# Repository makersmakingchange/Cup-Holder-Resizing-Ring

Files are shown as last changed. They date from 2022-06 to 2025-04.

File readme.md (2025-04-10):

# Cup Holder Resizing Ring
The Cup Holder Resizing Ring is a 3D printed ring used to reduce the diameter of the opening of a cup holder. The design can be modified in OpenSCAD by inputing the appropriate dimensions.

Picture of Cup Holder Resizing Ring printed in black PLA.

## More info at
- [Makers Making Change Project Page](https://makersmakingchange.com/project/cup-holder-resizing-ring/)

## How to Obtain a Cup Holder Resizing Ring
### 1. Do it Yourself (DIY) or Do it Together (DIT)

This is an open-source assistive technology, so anyone is free to build it. All of the files and instructions required to build the <Device-Name> are contained within this repository. Refer to the Maker Checklist below.

### 2. Request a build of this device

If you would like to obtain a Cup Holder Resizing Ring , you may submit a build request through the [MMC Library Page](https://makersmakingchange.com/project/device-name/). The requestor is responsible for the cost of materials and any shipping.

### 3. How to build this device for someone else

If you have the skills and equipment to build this device, and would like to donate your time to create the switch for someone who needs it, visit the [MMC Maker Wanted](https://makersmakingchange.com/maker-wanted/) section.

## Getting Started

### 1. Read the Makers Checklist

[The Makers Checklist](https://github.com/makersmakingchange/Cup-Holder-Resizing-Ring/blob/main/Cup%20Holder%20Resizing%20Ring/Documentation/Cup_Holder_Resizing_Ring_Maker_Checklist.pdf) 

### 3. Print the 3D Printable components

The OpenSCAD file used to generate the device STL can be found in the [/Design_Files](/Design_Files) folder.

### 4. Put the ring into the intended cup holder.

## Files
### Documentation
| Document | Version | Link |
|---|---|---|
| Design Rationale | 1.02 | [Cup_Holder_Resizing_Ring_Design_Rationale](https://github.com/makersmakingchange/Cup-Holder-Resizing-Ring/blob/main/Cup%20Holder%20Resizing%20Ring/Documentation/Cup_Holder_Resizing_Ring_Design_Rationale.pdf) |
| Maker Checklist | 1.02 | [Cup_Holder_Resizing_Ring_Maker_Checklist](https://github.com/makersmakingchange/Cup-Holder-Resizing-Ring/blob/main/Cup%20Holder%20Resizing%20Ring/Documentation/Cup_Holder_Resizing_Ring_Maker_Checklist.pdf) | |
| 3D Printing Guide | 1.02 | [Cup_Holder_Resizing_Ring_3D_Printing_Guide](https://github.com/makersmakingchange/Cup-Holder-Resizing-Ring/blob/main/Cup%20Holder%20Resizing%20Ring/Documentation/Cup_Holder_Resizing_Ring_3D_Print_Guide.pdf) |
| User Guide | 1.02 | [Cup_Holder_Resizing_Ring_User_Guide](https://github.com/makersmakingchange/Cup-Holder-Resizing-Ring/blob/main/Cup%20Holder%20Resizing%20Ring/Documentation/Cup_Holder_Resizing_Ring_User_Guide.pdf) |
| Changelog | 1.02 | [Cup_Holder_Resizing_Ring_Changelog](https://github.com/makersmakingchange/Cup-Holder-Resizing-Ring/blob/main/Cup%20Holder%20Resizing%20Ring/Documentation/Cup_Holder_Resizing_Ring_ChangeLog.pdf) |

### Design Files
[CAD File](https://github.com/makersmakingchange/Cup-Holder-Resizing-Ring/tree/main/Cup%20Holder%20Resizing%20Ring/Design_Files)

## Attribution
Designers:
 - Makers Making Change

## License
Everything needed or used to design, make, test, or prepare the Cup Holder Resizing Ring is licensed under the CERN 2.0 Permissive license <https://ohwr.org/project/cernohl/wikis/Documents/CERN-OHL-version-2> (CERN-OHL-P) . 

<br /><span xmlns:dct="http://purl.org/dc/terms/" property="dct:title"><Device-Name></span> by <a xmlns:cc="http://creativecommons.org/ns#" href="www.makersmakingchange.com" property="cc:attributionName" rel="cc:attributionURL">Neil Squire</a> is licensed under a <a rel="license" href="http://creativecommons.org/licenses/by-sa/4.0/">Creative Commons Attribution-ShareAlike 4.0 International License</a>.

---
<!-- ABOUT MMC START -->
## About Us
Makers Making Change Logo

Makers Making Change is an initiative of [Neil Squire](https://www.neilsquire.ca/), a Canadian non-profit that helps people with disabilities.

We are committed to creating a network of volunteer makers who support people with disabilities in their communities through 3D printing assistive devices. Check out our library of free, open-source assistive technologies with parts and build instructions.

 - Website: [www.MakersMakingChange.com](https://www.makersmakingchange.com/)
 - GitHub: [https://github.com/makersmakingchange](https://github.com/makersmakingchange)
 - Twitter: [@makermakechange](https://twitter.com/makermakechange)
 - Instagram: [@makersmakingchange](https://www.instagram.com/makersmakingchange)

## How you can get involved
1. Help design a solution 
2. Help build a device request

## Contact Us

For technical questions, to get involved, or share your experience we encourage you to visit the [MMC Website](https://www.makersmakingchange.com/), [MMC Forum](https://makersmakingchange.com/forum), or contact info@makersmakingchange.com

<!-- ABOUT MMC END -->

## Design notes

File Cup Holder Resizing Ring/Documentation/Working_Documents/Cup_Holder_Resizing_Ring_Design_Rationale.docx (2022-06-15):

# Introduction

There are many open-source and commercial options available for cup holders, as well as built in cup holders on many structures and devices. However, with the varying sizing of beverages you can buy today, some cup holders will not hold your drink securely, so a way to modify the size is required.

# Research

There are many existing cup holder designs as well as a few open-source ones. Some models are adjustable, but typically cost more or are expensive/difficult to make.

https://makersmakingchange.com/resource/device-selection-guide-cup-holders/ - Contains many of the existing commercial devices found during research as well as the opensource devices in the MMC library.

Adjustable Ram Mount Cup Holder $73.69 (https://www.amazon.ca/RAM-Mounts-RAP-B-417BU-Level-Diameter/dp/B01N2Y8ZJQ?s=sports) – Is adjustable to fit various beverage containers, but very high in cost.

# Requirements

1. Shall be able to modify the size of existing cup holders.
2. Shall be easy to vary the dimensions to custom fit for different cup holders and beverage containers.

# Ideation

Component 1:

Resizing Ring: A custom printed ring that fits into the cup holder and effectively reduces the diameter of the cup holder to better fit a smaller beverage container.

# Prototyping

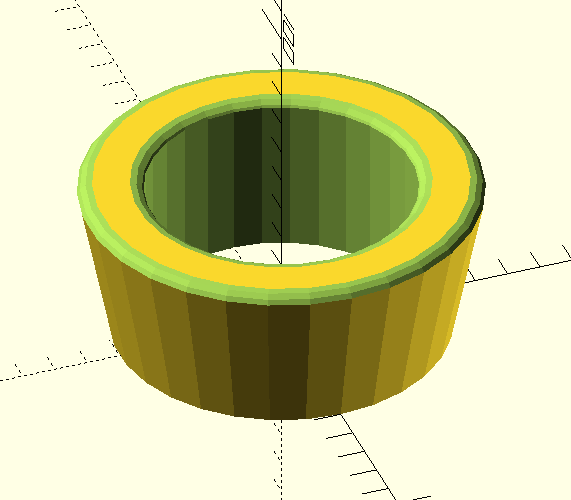
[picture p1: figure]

Designed in OpenSCAD, the Cup Holder Resizing Ring can be modified according to the measurements of the top and bottom radii, and height of the cup holder, as well as the radii of where the beverage container will sit in the holder.

# Final Design

- Updated the OpenSCAD file to include sliders for adjusting dimensions, and added dimensions for specific cup holders to the user quick guide and 3D print guide.
- Increased the resolution of the OpenSCAD model
- Changed the measurement input in the model from Radius to Diameter.

# Opportunities for Improvement

- Increase the number of presets
- Make the design so it can accommodate varying sizes of beverage containers once printed
  - Soft flaps or varying radius (like a camera iris)
- Add in the option for a bottom so open-ended cup holders can hold cans.

# Credited Resources Used In Development

- Idea came from Marc Hache and the ring he made for the cup holder in his Walker tray design.

© 2021 by Neil Squire. This work is licensed under the CC BY SA 4.0 License: http://creativecommons.org/licenses/by-sa/4.0 Files available at https://makersmakingchange.com/project/cup-holder-resizing-ring/ Page 1 of 1

V1.02 | June 2022 Cup Holder Resizing Ring Design Rationale

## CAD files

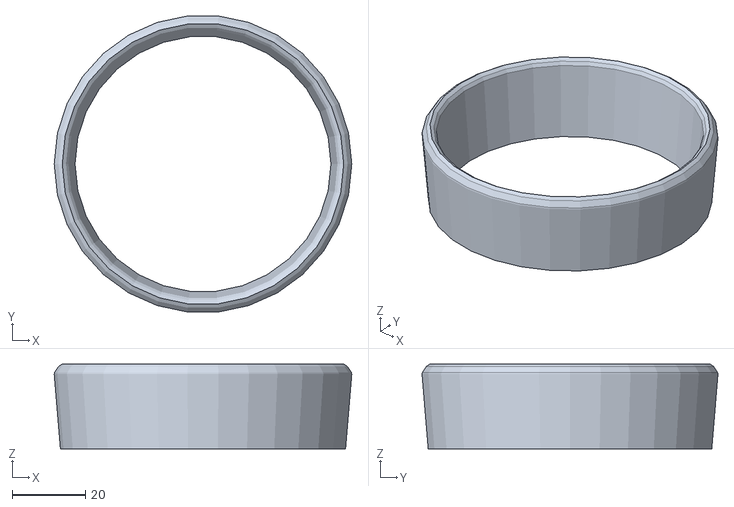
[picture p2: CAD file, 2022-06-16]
Cup Holder Resizing Ring/Design_Files/Example STL for Universal Travel Coffee Gimbal.stl
81.4 x 81.0 x 23.2

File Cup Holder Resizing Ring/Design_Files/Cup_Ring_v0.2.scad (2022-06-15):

// Cup Holder Adapter
//
// Written by Neil Squire / Makers Making Change
// This work is licensed under the CC BY SA 4.0 License: http://creativecommons.org/licenses/by-sa/4.0 

//  Files available at https://makersmakingchange.com/project/cup-holder-resizing-ring/

//
// This design is used to create a 3D printed adapter to reduce the size of a hole in a cup/bottle holder to better sure the beverage container.
//
//


/*[Cup Dimensions]*/
Lower_Cup_Diameter=40; // Lower cup diameter [mm]
Upper_Cup_Diameter=40; //  Upper cup diameter [mm]

/*[Holder Dimensions]*/
Lower_Holder_Diameter=50; // Lower holder radius [mm]
Upper_Holder_Diameter=60; // Upper holder  radius [mm]
Height=50; //          Holder depth [mm]



/*[Hidden]*/

// Misc variables
fudge = 0.005;

$fa=0.5;

difference() // A - B
{
    difference() // A
    {          
        difference() 
        {           
            cylinder(Height,Lower_Holder_Diameter/2,Upper_Holder_Diameter/2);
            cylinder(Height+fudge*2,Lower_Cup_Diameter/2,Upper_Cup_Diameter/2);
        }            
        rotate([0,180,0])
        {
            rotate_extrude()
            {
                translate([Upper_Cup_Diameter/2+4,-Height+5,0])
                {  
                    difference()
                    {
                        translate([-5,-5,0])
                        square(5,5);    
                        circle(r=5);
                    }
                }
            }
        }   
    }
    rotate([0,0,0]) // B
    {
        rotate_extrude()
        {
            translate([Upper_Holder_Diameter/2-5,Height-5,0])
            {
                difference()
                {   
                    translate([0,0,0])
                    square(5,5);   
                    circle(r=5);
                }
            }
        }
    }
}

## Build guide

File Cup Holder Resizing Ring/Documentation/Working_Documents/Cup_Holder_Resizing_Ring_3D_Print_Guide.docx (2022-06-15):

# 3D Printing Summary

Metrics | *Configuration 1*
Total Print Time (min) | Dependent on STL dimensions
Total Number of Components | 1
Typical Total Mass (g) | 100
Typical Number of Print Setups | 1

Specifications

Input the desired dimensions into OpenSCAD based on the cup and cup holder dimensions. Note that there are four radii and one height measurement. When measuring the radius, ensure the cup measurements line up with the height on the cup that should sit in the cup holder.

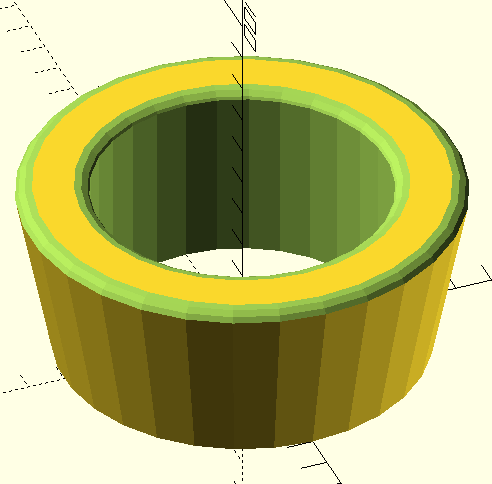
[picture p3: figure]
Photo showing the dimensions for editing the Cup Holder Resizing Ring.

Height

Lower Holder Diameter

Lower Cup Diameter

Upper Holder Diameter

Upper Cup Diameter

Cup Holder | Lower Diameter [mm] | Upper Diameter [mm] | Height [mm]
Cup Holder for Walker (https://makersmakingchange.com/assistive-devices/?_sf_s=cup%20holder) | 78 | 81 | 64
Swivel Wheelchair Cup Holder (https://makersmakingchange.com/project/swivel-wheelchair-cup-holder/) | 74 | 74 | 85
Universal Travel Coffee Gimbal (https://makersmakingchange.com/project/universal-travel-coffee-gimbal/) | 78 | 84 | 24

# 3D Printing Settings

Print File Name | Qty | Total Print Time (hr:min) | Mass (g) | Infill (%) | Support | Layer Height/ Nozzle Diameter(mm) | Notes
Cup_Ring_v0.2.stl | 1 | Dependent on STL dimensions. Likely 1 hour minimum | Dependent on STL dimensions. | 5 | N | 0.2/0.4 | Print in given orientation.

# Post-Processing

- Clean any stringing or filament strands from the print.

# Customization Options

- Ask the user if they have any colour preferences.
- Ask the user for the required dimensions to customize the STL appropriately to fit both their cup holder and beverage container.

# Examples of Quality Prints:

Photos of Component 1:

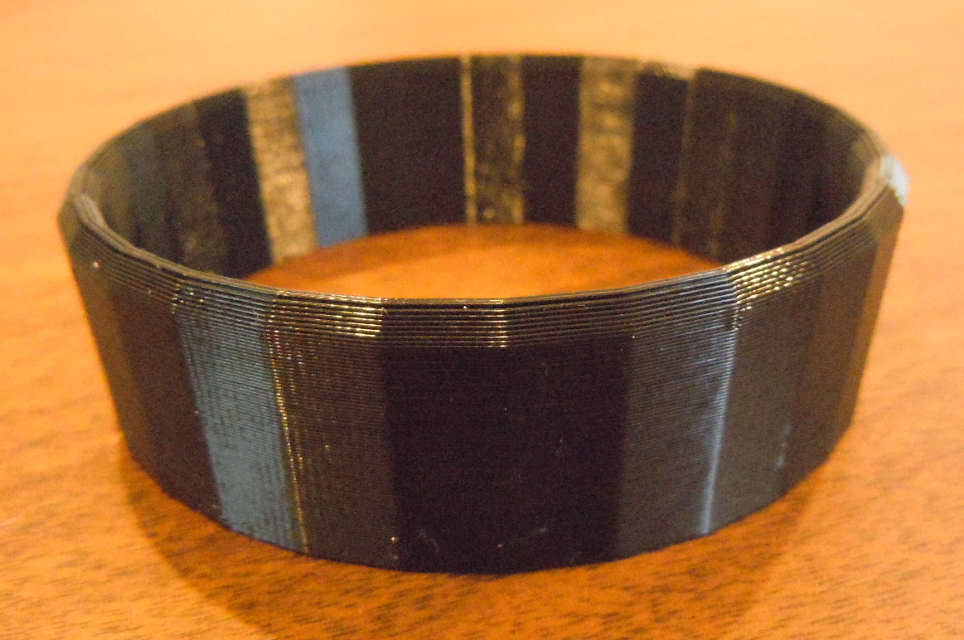
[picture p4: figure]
A picture containing an example of a quality print of the Cup Holder Resizing Ring.

© 2021 by Neil Squire. This work is licensed under the CC BY SA 4.0 License: http://creativecommons.org/licenses/by-sa/4.0 Files available at https://makersmakingchange.com/project/cup-holder-resizing-ring/ Page 1 of 2

V1.02 | June 2022 Cup Holder Resizing Ring 3D Printing Guide

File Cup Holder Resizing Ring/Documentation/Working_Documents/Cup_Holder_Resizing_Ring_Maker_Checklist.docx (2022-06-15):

# Maker To Do List

- Ask User Preferences for colour
- Ask user for beverage container dimensions and cup holder dimensions.
  - Depth of the Cup Holder
  - Inner radii at the top and bottom of the Cup Holder
  - Outer radii of the beverage container where it should line up with the top and bottom of the Resizing Ring.
- Print and deliver the device.

# Items to Give to User

- User Quick Guide
- Resizing Ring

© 2021 by Makers Making Change. This work is licensed under the CC BY SA 4.0 License: http://creativecommons.org/licenses/by-sa/4.0 Files available at https://makersmakingchange.com/project/cup-holder-resizing-ring/ Page 1 of 1

V1.02 | June 2022 Cup Holder Resizing Ring Maker Checklist

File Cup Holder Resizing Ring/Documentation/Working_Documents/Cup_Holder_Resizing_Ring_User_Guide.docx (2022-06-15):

## Introduction

The Cup Holder Resizing Ring is used to modify existing cup holders to hold smaller sized cups than intended. It can be used with mounted cup holders, or even built-in cups holders such as ones in a car.

## Features

The Cup Holder Resizing Ring decreases the inner diameter of a cup holder. It has rounded fillets on the upper edge to help guide the cup into place and reduce exposed sharp corners.

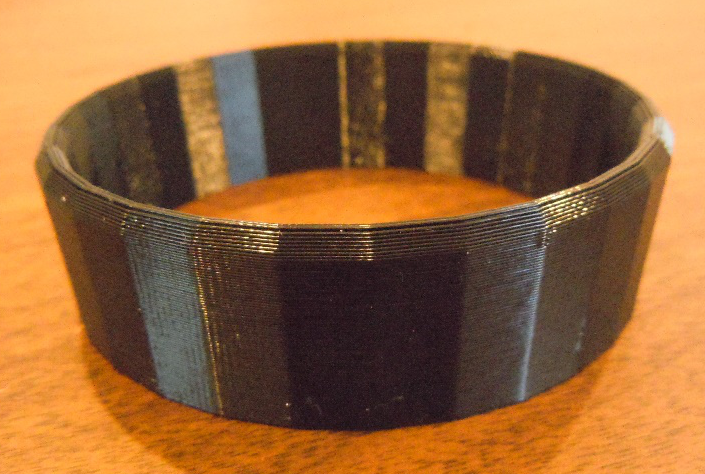
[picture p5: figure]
A picture containing a Cup Holder Resizing Ring printed in black PLA.
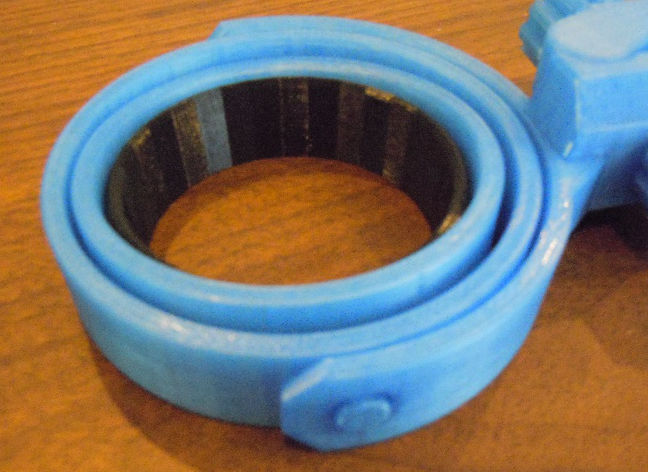
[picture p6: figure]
A picture containing a Cup Holder Resizing ring printed in black PLA sitting in a Universal Travel Coffee Gimbal printed in blue PLA.

## Usage

Input the proper dimensions into the OpenSCAD file and then print out the device. The ring simply fits into the cup holder and subsequently, the desired cup/beverage container into the ring.

## Compatibility

The Cup Holder Resizing Ring can be used to modify any cup holder for a smaller diameter cup.

## Specifications

The following table shows the dimensions for the cup holders in the MMC library. The cup dimensions will have to be measured and input in addition to any of these. If the cup holder is not from the MMC library, it will also need to be measured.

Cup Holder | Lower Diameter [mm] | Upper Diameter [mm] | Height [mm]
Cup Holder for Walker (https://makersmakingchange.com/assistive-devices/?_sf_s=cup%20holder) | 78 | 81 | 64
Swivel Wheelchair Cup Holder (https://makersmakingchange.com/project/swivel-wheelchair-cup-holder/) | 74 | 74 | 85
Universal Travel Coffee Gimbal (https://makersmakingchange.com/project/universal-travel-coffee-gimbal/) | 78 | 84 | 24

## Cleaning

Wipe the ring down with a damp c loth to clean off any spills. Do not wash with hot water.

© 2021 by Neil Squire. This work is licensed under the CC BY SA 4.0 License: http://creativecommons.org/licenses/by-sa/4.0 Files available at https://makersmakingchange.com/project/cup-holder-resizing-ring/ Page 2 of 3

V1.02 | June 2022 Cup Holder Resizing Ring user Quick Guide

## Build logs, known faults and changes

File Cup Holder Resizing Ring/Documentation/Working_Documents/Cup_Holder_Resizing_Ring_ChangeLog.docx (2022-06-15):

# Version 1.0 | May 2022

- General shape created in OpenSCAD.

# Version 1.01 | May 2022

- Licencing disclaimer added to OpenSCAD file.

# Version 1.02 | June 2022

- Sizing slider added for ease of customisation.
- Resolution on model increased

© 2021 by Neil Squire . This work is licensed under the CC BY SA 4.0 License: http://creativecommons.org/licenses/by-sa/4.0 Files available at https://makersmakingchange.com/project/cup-holder-resizing-ring/ Page 1 of 1

V1.02 | June 2022 Cup Holder Resizing Ring changelog
